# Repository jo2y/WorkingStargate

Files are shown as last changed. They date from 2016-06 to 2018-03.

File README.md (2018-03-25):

My version of the "Working" [Stargate MK II](http://www.thingiverse.com/thing:1603423) created by [Glitch](https://www.thingiverse.com/Glitch/about).

Rough list of changes made by me.
*   I rewrote most of the arduino code.
*   I merged some of the ideas from [Carasibana](
    https://www.thingiverse.com/Carasibana/about)'s [version](
    https://www.thingiverse.com/make:104604) and another build I can no longer
    find on thingiverse. This second one is where I got the audio parts.

Some videos of my completed build:
*   https://youtu.be/wpxE08CTAZk
*   https://youtu.be/otdeWcTs9Uo

I no longer have this gate. I donated it to a Stargate focused charity auction.
I plan to build a new one eventually.

Note: I am no claiming ownership of all the work in this repository, specifically the design.

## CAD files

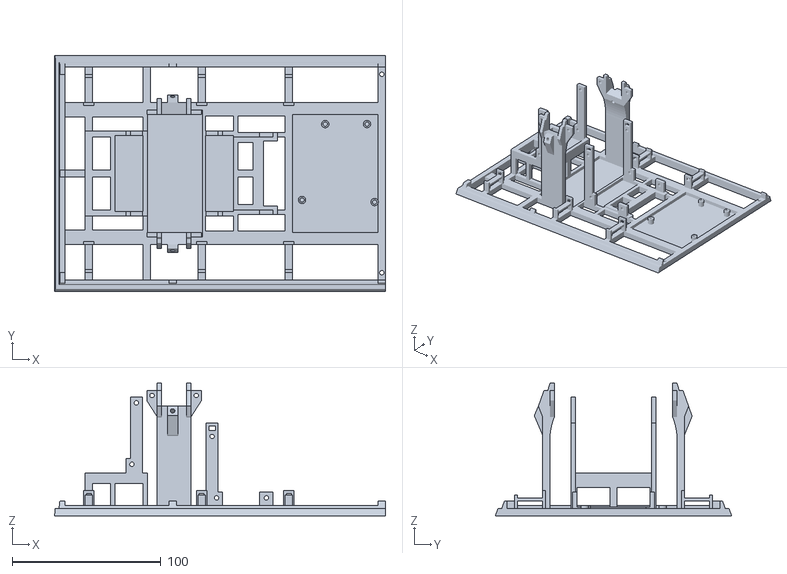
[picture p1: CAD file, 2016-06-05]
Stargate_mk2/base_full_x1.stl
222.5 x 158.8 x 89.1

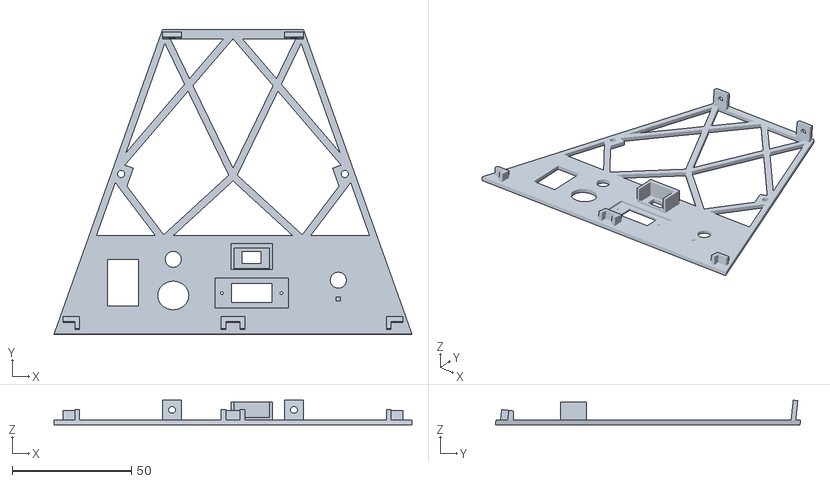
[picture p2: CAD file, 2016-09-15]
Stargate_mk2/base_rear_w_panel_v2.stl
149.9 x 127.8 x 10.4

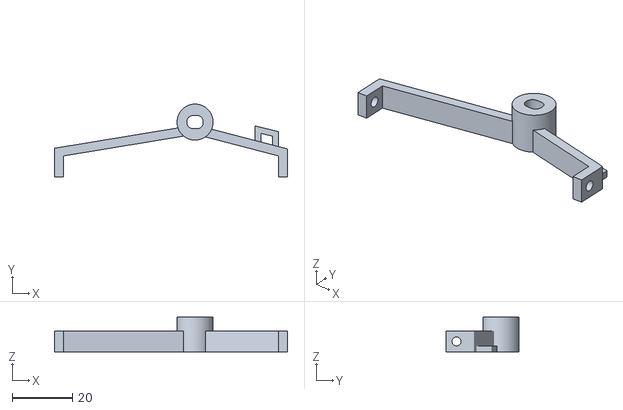
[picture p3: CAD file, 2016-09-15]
Stargate_mk2/ldr_1_enlarged_v2.stl
77.5 x 24.3 x 11.6

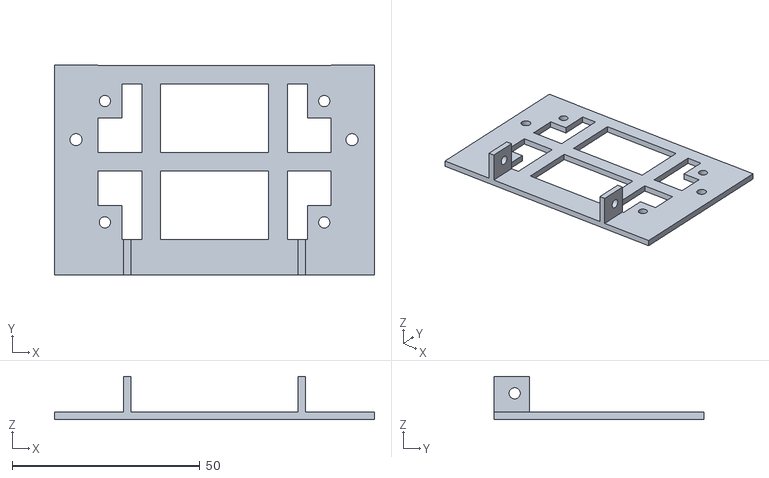
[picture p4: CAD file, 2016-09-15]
Stargate_mk2/circuit_board_permaproto.stl
85.2 x 55.9 x 11.5

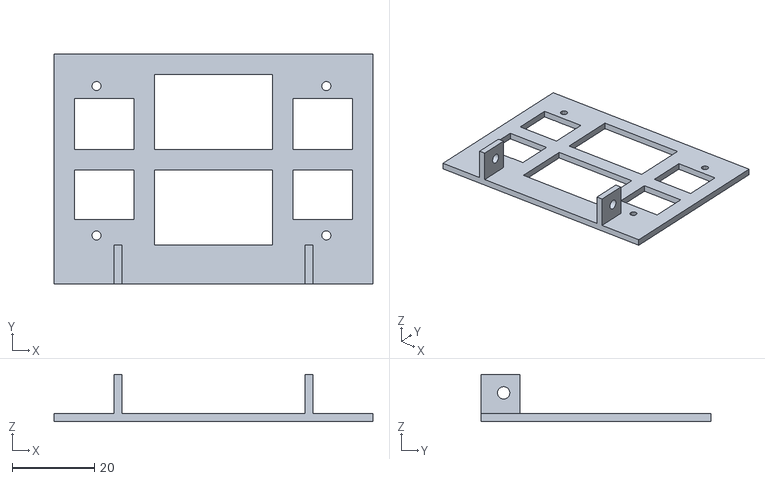
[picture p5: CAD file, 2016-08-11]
Stargate_mk2/circuit_board_4cm_x_6cm.stl
77.4 x 55.8 x 11.5

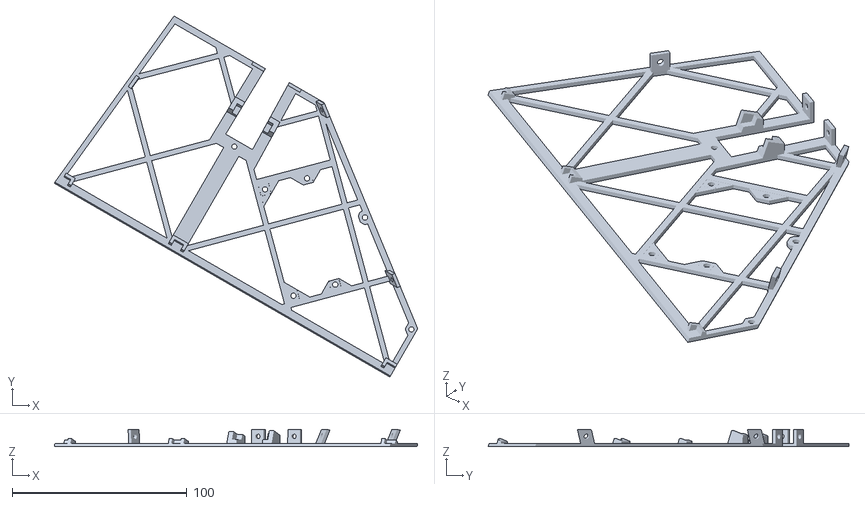
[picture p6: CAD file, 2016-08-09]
Stargate_mk2/base_right_w_speaker.stl
208.1 x 206.7 x 9.98

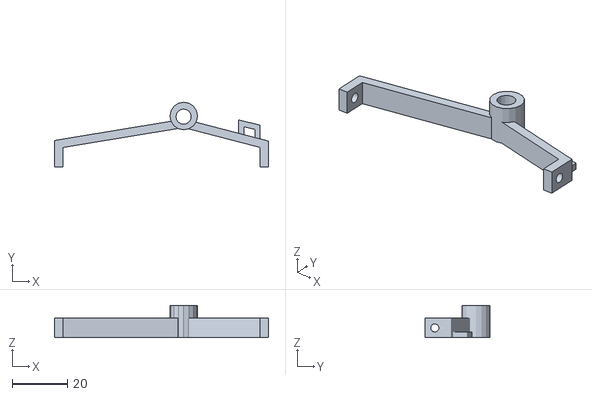
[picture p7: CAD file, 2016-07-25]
Stargate_mk2/ldr_x1_enlarged.stl
77.5 x 23.4 x 11.6

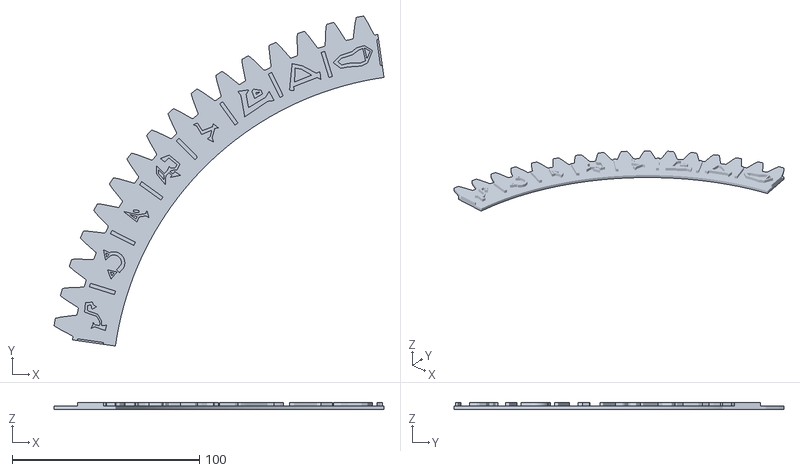
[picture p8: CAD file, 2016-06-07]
Stargate_mk2/symbol_2_x1.stl
176.0 x 176.0 x 4.00

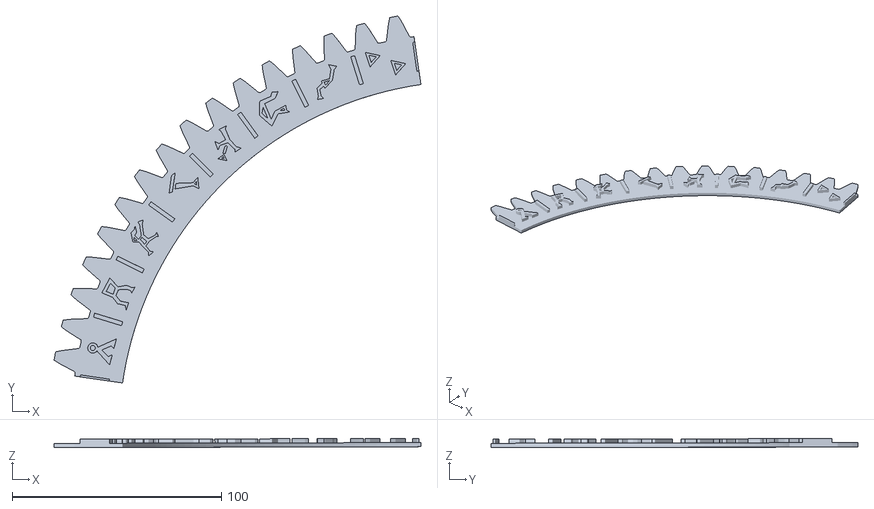
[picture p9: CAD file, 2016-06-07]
Stargate_mk2/symbol_1_x1.stl
175.4 x 175.4 x 4.42

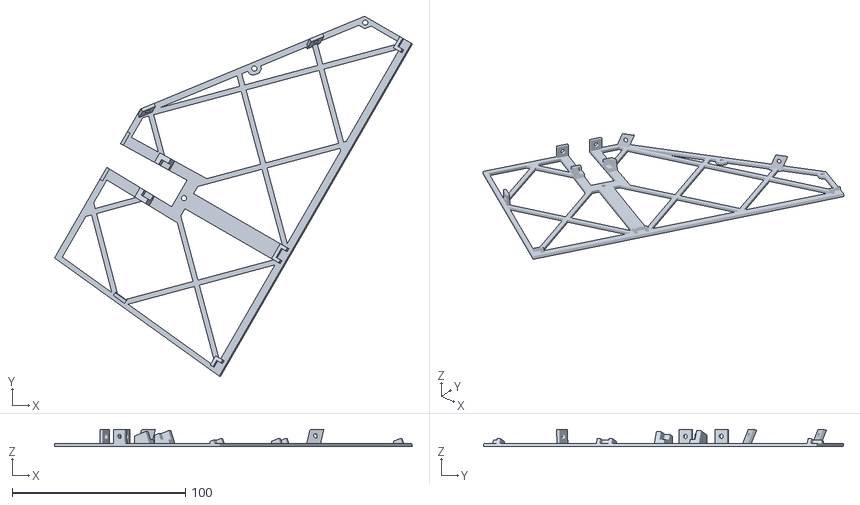
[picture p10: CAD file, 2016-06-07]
Stargate_mk2/base_r_2_x1.stl
206.7 x 208.1 x 9.98

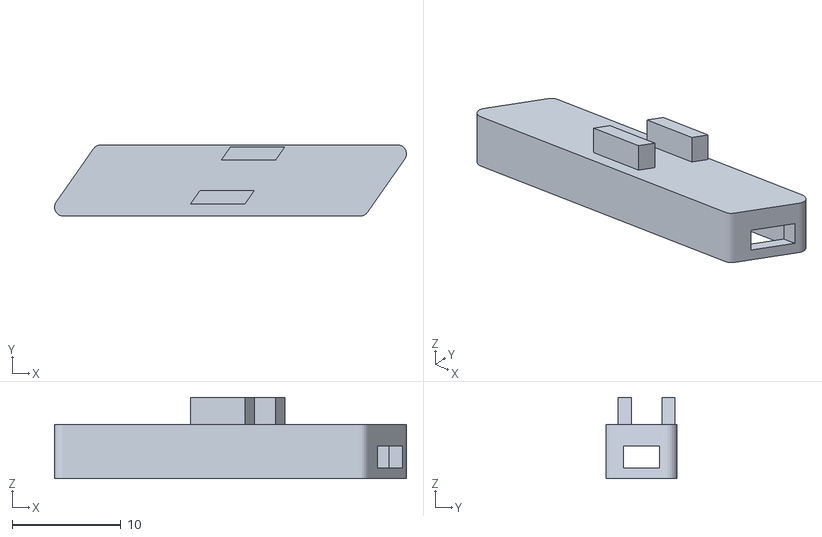
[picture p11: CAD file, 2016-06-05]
Stargate_mk2/rail_r_2_x4.stl
32.4 x 6.56 x 7.48

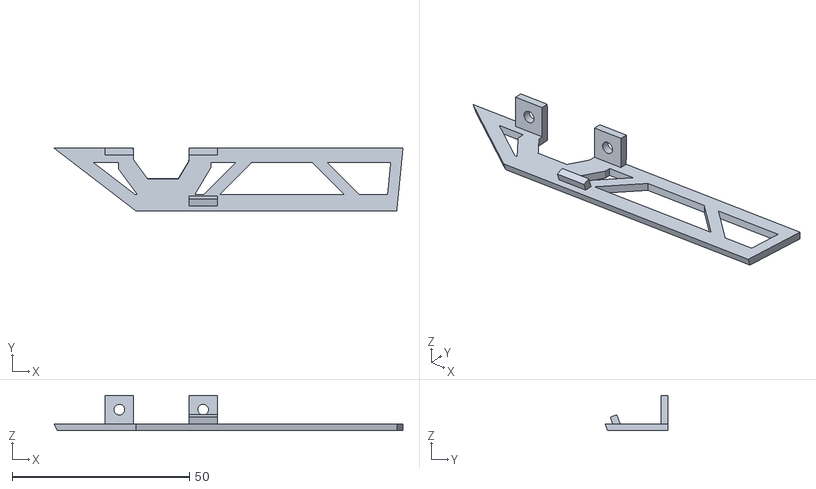
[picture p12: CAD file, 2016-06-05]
Stargate_mk2/base_r_3_x1.stl
98.5 x 17.7 x 9.90

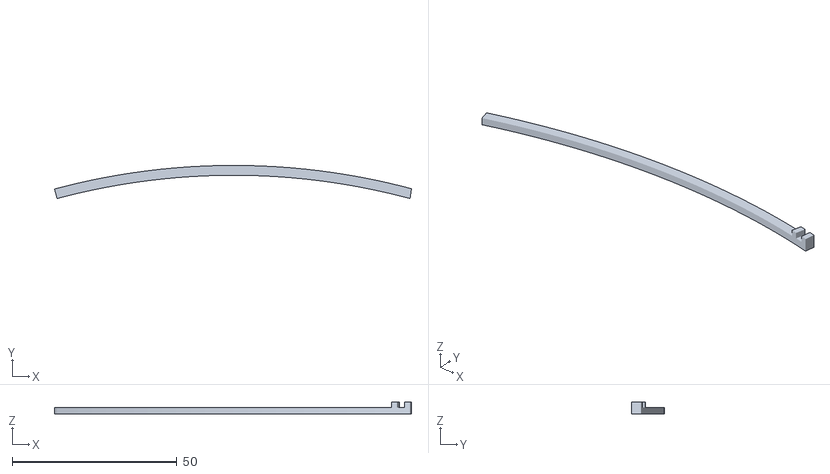
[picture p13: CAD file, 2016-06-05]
Stargate_mk2/ring_4_x1.stl
108.4 x 10.1 x 3.64

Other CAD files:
Stargate_mk2/base_left_w_speaker.stl
Stargate_mk2/symbol_3_x1.stl
Stargate_mk2/symbol_4_x1.stl
Stargate_mk2/base_l_2_x1.stl
Stargate_mk2/circuit_x.stl
Stargate_mk2/base_half_back_x1.stl
Stargate_mk2/base_half_front_x1.stl
Stargate_mk2/base_l_1_x1.stl
Stargate_mk2/base_l_3_x1.stl
Stargate_mk2/base_r_1_x1.stl
Stargate_mk2/base_rear_w_panel.stl
Stargate_mk2/base_rear_x1.stl
Stargate_mk2/chevron_1_x9.stl
Stargate_mk2/chevron_2_a_x9.stl
Stargate_mk2/chevron_2_b_x9.stl
Stargate_mk2/chevron_2_c_x9.stl
Stargate_mk2/chevron_3_a_x9.stl
Stargate_mk2/chevron_3_b_x9.stl
Stargate_mk2/chevron_3_c_x9.stl
Stargate_mk2/chevron_4_x9.stl
Stargate_mk2/gate_1_a_x8.stl
Stargate_mk2/gate_1_b_x1.stl
Stargate_mk2/gate_2_a_x8.stl
Stargate_mk2/gate_2_b_x1.stl
Stargate_mk2/gate_3_a_x1.stl
Stargate_mk2/gate_3_b_x6.stl
Stargate_mk2/gate_3_c_x1.stl
Stargate_mk2/gate_3_d_x1.stl
Stargate_mk2/gate_4_a_x1.stl
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

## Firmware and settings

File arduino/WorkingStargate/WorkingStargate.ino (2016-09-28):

// Configurable values
//
// LED and Pixel Related Settings
//
// How long should the locking chevron be engaged?
#define LOCK_DELAY 1500  // in milliseconds

//
// Arduino Pin Mappings
//
// This section defines which arduino pin connects to which electronic device.
// The data pin for the chain of NeoPixels around the gate.
#define GATE_PIXELS 5

// The left and right ramp lights. Connected to the audio board GPIO pins.
#define LEFT_RAMP 7
#define RIGHT_RAMP 6

// DHD buttons
#define DHD_OUTER A2  // Serial pin 4
#define DHD_INNER A3  // Serial pin 5
// The data pin for the chain of NeoPixels around the DHD.
#define DHD_PIXELS 8

// Calibration LDR and LED
#define CAL_LDR A1
#define CAL_LED 10

// These are the pins used for the music maker shield. If you're using the
// adafruit mp3 shield, leave as-is.
#define AUDIO_SHIELD_RESET -1  // VS1053 reset pin (unused!)
#define AUDIO_SHIELD_CS 7      // VS1053 chip select pin (output)
#define AUDIO_SHIELD_DCS 6     // VS1053 Data/command select pin (output)
#define AUDIO_CARDCS 4         // Card chip select pin
// DREQ should be an Int pin, see http://arduino.cc/en/Reference/attachInterrupt
#define AUDIO_DREQ 3           // VS1053 Data request, ideally an Interrupt pin
#define AUDIO_VOLUME A0
// MINVOL/MAXVOL should be (0, 254) with 0 being the loudest and 254 as silence.
#define MINVOL 90
#define MAXVOL 0

// Unusable pins.
// These pins have double duty. Annotating them so the dual role is not
// forgotten.
#define RX 0
#define TX 1
#define MOSI 11
#define MISO 12
#define SCK 13
#define SDA A4
#define SCL A5

//
// Stepper Motor Settings
//
// The Glyph motor moves the ring with the symbols and the Chevron motor causes
// the top chevron to move.
// If you are using adafruit stepper motors, 200.0 is likely the correct value.
// If your motor doesn't list the number of steps, look for a degrees per step
// value. Divide 360 / degrees to get the value for here. (Adafruit motors are
// 1.8 degrees per step.
#define GLYPH_MOTOR_STEPS 200.0
#define CHEVRON_MOTOR_STEPS 200.0
// The port for the adafruit motor shield. If the stepper motor is connected to
// M1/M2 set 1, for M3/M4 set 2.
#define GLYPH_MOTOR_PORT 1
#define CHEVRON_MOTOR_PORT 2
// How fast should the motors be moved? The values here are likely suitable.
#define GLYPH_MOTOR_SPEED 10  // RPMs
#define CHEVRON_MOTOR_SPEED 10  // RPMs

//
// Audio Settings
//
// The SOUND_* defines specify files on the SD card that should be played at
// certain times in a dialing sequence.
#define SOUND_CHEVRON_LOCK "CHEVRON.MP3"
#define SOUND_LONG_SPIN "ROLL.MP3"
#define SOUND_SHORT_SPIN "ROLL.MP3"
#define SOUND_WORMHOLE_CLOSING "CLOSE.MP3"
#define SOUND_WORMHOLE_OPENING "OPEN.MP3"
#define SOUND_WORMHOLE_OPEN "WORMHOLE.MP3"

//
// Debugging Settings
//
// Set DEBUG to 1 to enable Serial output, 0 to disable
#define DEBUG 0

#if DEBUG
#define debug(line) Serial.print(line)
#define debugln(line) Serial.println(line)
#else
#define debug(line)
#define debugln(line)
#endif

//
// STL Design Settings.
// Values related to the printed models. These would only change if the STL
// files were redesigned.
#define NUM_GLYPHS 39.0
#define GLYPH_GEAR_TEETH 13.0
#define GLYPH_RING_TEETH 78.0
#define GLYPH_GEAR_RATIO ( GLYPH_RING_TEETH / GLYPH_GEAR_TEETH )
#define GLYPH_RING_STEPS ( GLYPH_MOTOR_STEPS * GLYPH_GEAR_RATIO )
#define STEPS_PER_GLYPH ( GLYPH_RING_STEPS / NUM_GLYPHS )
#define NUM_PIXELS 9
#define TOP_CHEVRON 4
#define LOCK_STEPS 10

// No user servicable values below here.
#include <SD.h>
#include <Adafruit_MCP23008.h>
#include <Adafruit_MotorShield.h>
#include <Adafruit_NeoPixel.h>
#include <Adafruit_VS1053.h>

// Global objects
Adafruit_NeoPixel pixels = Adafruit_NeoPixel(
    NUM_PIXELS, GATE_PIXELS, NEO_RGB + NEO_KHZ800);
Adafruit_MotorShield AFMS = Adafruit_MotorShield();
Adafruit_StepperMotor *SMGlyph = AFMS.getStepper(
    GLYPH_MOTOR_STEPS, GLYPH_MOTOR_PORT);
Adafruit_StepperMotor *SMChevron = AFMS.getStepper(
    CHEVRON_MOTOR_STEPS, CHEVRON_MOTOR_PORT);
Adafruit_VS1053_FilePlayer audio = Adafruit_VS1053_FilePlayer(
    AUDIO_SHIELD_RESET, AUDIO_SHIELD_CS, AUDIO_SHIELD_DCS,
    AUDIO_DREQ, AUDIO_CARDCS);
Adafruit_MCP23008 extra_pins = Adafruit_MCP23008();

// Colors
uint32_t off = pixels.Color(0, 0, 0);
uint32_t on = pixels.Color(0, 255, 0);

// Pixel related functions

void initPixels() {
  pixels.begin();
  pixelsOff();
}

void lockChevron(int chevron) {
  pixels.setPixelColor(TOP_CHEVRON, on);
  pixels.show();
  debugln(F("Lowering Top Chevron."));
  startSound(SOUND_CHEVRON_LOCK);
  
  SMChevron->step(LOCK_STEPS, BACKWARD, SINGLE);
  delay(LOCK_DELAY);
  waitSound();
  debugln(F("Raising Top Chevron."));
  SMChevron->step(LOCK_STEPS, FORWARD, SINGLE);
  pixels.setPixelColor(TOP_CHEVRON, off);
  pixels.setPixelColor(chevron, on);
  pixels.show();
}

void pixelsOff() {
  for (int i = 0; i < NUM_PIXELS; i++) {
    pixels.setPixelColor(i, off);
  }
  pixels.show();
}

void initRampLights() {
  debugln(F("Initializing Ramp Lights."));
  audio.GPIO_pinMode(LEFT_RAMP, OUTPUT);
  audio.GPIO_pinMode(RIGHT_RAMP, OUTPUT);
}

void toggleRampLights(boolean left, boolean right) {
  debug(F("Turning left ramp: "));
  debugln(left ? F("On") : F("Off"));
  debug(F("Turning right ramp: "));
  debugln(right ? F("On") : F("Off"));
  audio.GPIO_digitalWrite(LEFT_RAMP, left ? HIGH : LOW);
  audio.GPIO_digitalWrite(RIGHT_RAMP, right ? HIGH : LOW);
}

// Gate Movement functions

void initMotors() {
  AFMS.begin();
  SMGlyph->setSpeed(GLYPH_MOTOR_SPEED);
  SMChevron->setSpeed(CHEVRON_MOTOR_SPEED);
  debugln(F("Raising Top Chevron."));
  SMChevron->step(10, FORWARD, SINGLE);
}

void calibrateGlyphs() {
  debugln(F("Starting Glyph Calibration."));
  // Increase the motor speed to calibrate quickly.
  SMGlyph->setSpeed(max(GLYPH_MOTOR_SPEED, 60));
  pinMode(CAL_LDR, INPUT_PULLUP);
  pinMode(CAL_LED, OUTPUT);
  digitalWrite(CAL_LED, LOW);
  float setpoint = 1024.0;
  unsigned int readings = 0;
  for (int i = 0; i < 10; ++i) {
    readings += analogRead(CAL_LDR);
    SMGlyph->step(1, BACKWARD, MICROSTEP);
  }
  setpoint = (readings / 10.0) * 0.5;
  debug(F("Setpoint: "));
  debugln(setpoint);
  digitalWrite(CAL_LED, HIGH);
  while (analogRead(CAL_LDR) > setpoint) {
    SMGlyph->step(1, FORWARD, MICROSTEP);
  }
  digitalWrite(CAL_LED, LOW);
  SMGlyph->release();
  SMGlyph->setSpeed(GLYPH_MOTOR_SPEED);
  debugln(F("Finishing Calibration."));
}

void rotateGate(int glyph, int chevron) {
  // The number of motor steps from the Earth glyph to each
  // list of glyphs in clockwise order.
  // http://rdanderson.com/stargate/glyphs/glyphs.htm
  // Explicitly declare the array size to ensure NUM_GLYPHS matches contents.
  int glyph_offsets[(int) NUM_GLYPHS] = {
    int( 0 * STEPS_PER_GLYPH), // Earth
    int(38 * STEPS_PER_GLYPH), // Crater
    int(37 * STEPS_PER_GLYPH), // Virgo
    int(36 * STEPS_PER_GLYPH), // Bootes
    int(35 * STEPS_PER_GLYPH), // Centaurus
    int(34 * STEPS_PER_GLYPH), // Libra
    int(33 * STEPS_PER_GLYPH), // Serpens Caput
    int(32 * STEPS_PER_GLYPH), // Norma
    int(31 * STEPS_PER_GLYPH), // Scorpio
    int(30 * STEPS_PER_GLYPH), // Cra
    int(29 * STEPS_PER_GLYPH), // Scutum
    int(28 * STEPS_PER_GLYPH), // Sagittarius
    int(27 * STEPS_PER_GLYPH), // Aquila
    int(26 * STEPS_PER_GLYPH), // Mic
    int(25 * STEPS_PER_GLYPH), // Capricon
    int(24 * STEPS_PER_GLYPH), // Pisces Austrinus
    int(23 * STEPS_PER_GLYPH), // Equuleus
    int(22 * STEPS_PER_GLYPH), // Aquarius
    int(21 * STEPS_PER_GLYPH), // Pegasus
    int(20 * STEPS_PER_GLYPH), // Sculptor
    int(19 * STEPS_PER_GLYPH), // Pisces
    int(18 * STEPS_PER_GLYPH), // Andromeda
    int(17 * STEPS_PER_GLYPH), // Triangulum
    int(16 * STEPS_PER_GLYPH), // Aries
    int(15 * STEPS_PER_GLYPH), // Perseus
    int(14 * STEPS_PER_GLYPH), // Cetus
    int(13 * STEPS_PER_GLYPH), // Taurus
    int(12 * STEPS_PER_GLYPH), // Auriga
    int(11 * STEPS_PER_GLYPH), // Eridanus
    int(10 * STEPS_PER_GLYPH), // Orion
    int( 9 * STEPS_PER_GLYPH), // Canis Minor
    int( 8 * STEPS_PER_GLYPH), // Monoceros
    int( 7 * STEPS_PER_GLYPH), // Gemini
    int( 6 * STEPS_PER_GLYPH), // Hydra
    int( 5 * STEPS_PER_GLYPH), // Lynx
    int( 4 * STEPS_PER_GLYPH), // Cancer
    int( 3 * STEPS_PER_GLYPH), // Sextans
    int( 2 * STEPS_PER_GLYPH), // Leo Minor
    int( 1 * STEPS_PER_GLYPH), // Leo
  };

  // Assume the gate starts with Earth at the top.
  static int curr_offset = glyph_offsets[0];
  int direction = (chevron % 2) ? FORWARD : BACKWARD;
  int steps = 0;

  // Bounds checking before we access glyph_offsets.
  glyph = constrain(glyph, 0, NUM_GLYPHS);

  int offset = glyph_offsets[glyph];
  if (direction == FORWARD) {
    steps = offset - curr_offset;
  } else if (direction == BACKWARD) {
    steps = curr_offset - offset;
  }
  // Keep the rotation within a single rotation of the gate.
  while (steps < 0) {
    steps += GLYPH_RING_STEPS;
  }
  while (steps > GLYPH_RING_STEPS) {
    steps -= GLYPH_RING_STEPS;
  }

  debug(F("Moving "));
  debug(steps);
  debug(F(" steps "));
  debug((direction == FORWARD) ? F("Forward") : F("Backward"));
  debug(F(" to glyph "));
  debug(glyph);
  debug(F(" for chevron "));
  debugln(chevron);
  startSound(SOUND_SHORT_SPIN);
  // TODO(jo2y): Update rotate to take into account partial steps.
  SMGlyph->step((int) steps, direction, SINGLE);
  stopSound(2000);
  curr_offset = glyph_offsets[glyph];
}

void initAudio() {
  debugln(F("Starting Audio."));
  if (!audio.begin()) {
    debugln(F("Audio shield did not initialize."));
#if DEBUG
    audio.dumpRegs();
#endif
  }
  setVolume();
  audio.useInterrupt(VS1053_FILEPLAYER_PIN_INT);
}

void setVolume() {
  static int oldvol = int((MINVOL + MAXVOL) / 2);
  byte attempts = 20;
  while (attempts > 0) {
    --attempts;
    int vol = analogRead(AUDIO_VOLUME);
    // analogRead will return (0, 1023) and setVolume takes (0, 254), but values
    // larger than 90 seem too quiet to hear, so scale (0, 1024) to (0, 90).
    // 0 is full volume and 254 is silence.
    // 255 will activate analog shutdown mode.
    vol = map(vol, 0, 1023, MINVOL, MAXVOL);
    // Sometimes we get noise from the ADC, so constrain the jumps in volume
    // to something sane. If the volume truly was changed a lot, we will
    // gradually converge on the new setting.
    vol = constrain(vol, oldvol - 5, oldvol + 5);
    if (oldvol != vol) {
      if (abs(oldvol - vol) > 2) {
        // Avoid spamming serial if the volume is fluctuating by a small amount
        // due to electrical noise.
        debug(F("Changing volume to: "));
        debugln(vol);
      }
      audio.setVolume(vol, vol);
    } else {
      debugln(F("Volume Stabilized."));
      return;
    }
    oldvol = vol;
  }
  debugln(F("Volume attempts exceeded."));
}

void startSound(const char *file) {
  debug(F("Playing file: "));
  debugln(file);
  setVolume();
  if (!audio.startPlayingFile(file)) {
    debug(F("Could not open file: "));
    debugln(file);
  }
}

void waitSound() {
  debugln(F("Waiting for track to end."));
  setVolume();
  while(audio.playingMusic) {
    delay(100);
    setVolume();
  }
}

void stopSound(int sleep) {
  debugln(F("Interrupting audio."));
  setVolume();
  delay(sleep);
  audio.stopPlaying();
}

void initSD() {
  debugln(F("Initializing SD Card."));
  SD.begin(AUDIO_CARDCS);
}

void initExtraPins() {
  debugln(F("Initializing the MCP23008."));
  extra_pins.begin();
  for (int x = 0; x < 8; ++x) {
    extra_pins.pinMode(x, INPUT);
    extra_pins.pullUp(x, HIGH);
  }
}

void dialAddress(byte *address, int length) {
  length = constrain(length, 0, 8);
  byte chevron = 5;
  byte max_chevron = 7;
  byte min_chevron = 1;
  if (length > 6) max_chevron = 8;
  if (length > 7) min_chevron = 0;
  debugln(F("Starting dialing sequence."));
  for (int position = 0; (position < length); ++position) {
    debug(F("Locking in Chevron "));
    debugln(chevron);
    byte glyph = address[position];
    glyph = constrain(glyph, 0, NUM_GLYPHS);
    rotateGate(glyph, chevron);
    lockChevron(chevron);
    ++chevron;
    if (chevron > max_chevron) chevron = min_chevron;
  }
  rotateGate(0, TOP_CHEVRON);
  lockChevron(chevron);
  openGate();
}

void openGate() {
  startSound(SOUND_WORMHOLE_OPENING);
  waitSound();
  startSound(SOUND_WORMHOLE_OPEN);
  waitSound();
  pixelsOff();
  startSound(SOUND_WORMHOLE_CLOSING);
  pixelsOff();
  waitSound();
}

void randomDialing() {
  // List of addresses provided by
  // http://www.rdanderson.com/stargate/glyphs/glyphs.htm
  // Addresses with missing symbols were skipped.
  byte milky_addresses[][6] = {
    {27, 7, 15, 32, 12, 30}, // Abydos
//    {20, 18, 11, 38, 10, 32}, // Apophis' Base
//    {20, 2, 35, 8, 26, 15}, // Camelot
//    {29, 3, 6, 9, 12, 16}, // Castiana
//    {29, 18, 19, 20, 21, 22}, // Sahal
//    {9, 2, 23, 15, 37, 20}, // Chulak
//    {14, 21, 16, 11, 30, 7}, // Clava Thesara Infinitas
//    {26, 20, 35, 32, 23, 4}, // Clava Thesara Infinitas (again?)
//    {3, 32, 16, 8, 10, 12}, // Destroyers
//    {28, 38, 35, 9, 15, 3}, // Edora
//    {30, 37, 9, 7, 18, 16}, // Euronda
//    {29, 8, 18, 22, 4, 25}, // Juna
//    {6, 16, 8, 3, 26, 25}, // Kallana
//    {26, 35, 6, 8, 23, 14}, // Kheb
//    {18, 2, 30, 12, 26, 33}, // K'Tau
//    {24, 12, 32, 7, 11, 34}, // Martin's Homeworld (destroyed)
//    {38, 28, 15, 35, 3, 19}, // NID Off-world Base
//    {28, 8, 16, 33, 13, 31}, // P2X-555
//    {38, 9, 28, 15, 35, 3}, // P34-353J
//    {19, 8, 4, 37, 26, 16}, // P3W-451 (Black hole planet)
//    {9, 26, 34, 27, 17, 21}, // P3X-118
//    {3, 28, 9, 35, 24, 15}, // P3X-562
//    {25, 8, 18, 29, 4, 22}, // P9C-372
//    {12, 36, 23, 18, 7, 27}, // PB5-926
//    {35, 3, 31, 29, 5, 17}, // Praclarush Taonas
//    {30, 19, 34, 9, 33, 18}, // Sangreal Planet
//    {33, 28, 23, 26, 16, 21}, // Tartarus
//    {6, 33, 27, 37, 11, 18}, // Tollan (destroyed)
//    {4, 29, 8, 22, 18, 25}, // Tollana
//    {3, 8, 2, 12, 19, 30}, // Vagon Brei
//    {9, 18, 27, 15, 21, 36}, // Unnammed Planet from Unending
  };
  
  // Special gate addresses.
//  byte earth[] = {28, 26, 5, 36, 11, 29};
//  byte othana[] = {11, 27, 23, 16, 33, 3, 9};

  static int chevron = 5;
  debugln(F("Starting dialing sequence."));
  debug(F("Locking in Chevron "));
  debugln(chevron);

  byte length = sizeof(milky_addresses[0]) / sizeof(byte);
  byte addresses = sizeof(milky_addresses) / length / sizeof(byte);
  byte *address = milky_addresses[random(addresses - 1)];
  debug(F("Dialing: "));
  for (int i = 0; i < length; ++i) {
    debug(address[i]);
    debug(F(", "));
  }
  debugln();
  dialAddress(address, length);
}

void setup() {
#if DEBUG
  Serial.begin(9600);
#endif
  debugln(F("Working Stargate MKII."));
  debugln(F("Initializing."));

  // Ideally we would use an analog pin that is not connected to anything else
  // to ensure the value is real random noise. However, all the pins are
  // allocated to something. Using CAL_LDR + AUDIO_VOLUME means randomness will
  // will be based on ambient light conditions and the last set volume.
  int seed = analogRead(CAL_LDR);
  debug(F("Random seed: "));
  debugln(seed);
  randomSeed(seed);

  initExtraPins();
  initPixels();
  initMotors();
  initAudio();
  initSD();
  initRampLights();
  toggleRampLights(true, true);
  calibrateGlyphs();
  debugln(F("Initialization Complete."));
}

void loop() {
  randomDialing();
}

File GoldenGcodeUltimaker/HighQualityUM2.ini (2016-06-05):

[profile]
layer_height = 0.06
wall_thickness = 1.2
retraction_enable = True
solid_layer_thickness = 1.2
fill_density = 0
print_speed = 50
print_temperature = 210
print_temperature2 = 0
print_temperature3 = 0
print_temperature4 = 0
print_temperature5 = 0
print_bed_temperature = 70
support = None
platform_adhesion = None
support_dual_extrusion = Both
wipe_tower = False
wipe_tower_volume = 15
ooze_shield = False
filament_diameter = 2.85
filament_diameter2 = 0
filament_diameter3 = 0
filament_diameter4 = 0
filament_diameter5 = 0
filament_flow = 100.0
nozzle_size = 0.4
retraction_speed = 40.0
retraction_amount = 4.5
retraction_dual_amount = 16.5
retraction_min_travel = 1
retraction_combing = All
retraction_minimal_extrusion = 0.05
retraction_hop = 0.1
bottom_thickness = 0.3
layer0_width_factor = 100
object_sink = 0.0
overlap_dual = 0.15
travel_speed = 200
bottom_layer_speed = 20
infill_speed = 0.0
solidarea_speed = 0.0
inset0_speed = 0.0
insetx_speed = 0.0
cool_min_layer_time = 5
fan_enabled = True
skirt_line_count = 1
skirt_gap = 3.0
skirt_minimal_length = 150.0
fan_full_height = 5.0
fan_speed = 100
fan_speed_max = 100
cool_min_feedrate = 10
cool_head_lift = True
solid_top = True
solid_bottom = True
fill_overlap = 15
perimeter_before_infill = False
support_type = Lines
support_angle = 60
support_fill_rate = 15
support_xy_distance = 0.7
support_z_distance = 0.15
spiralize = False
simple_mode = False
brim_line_count = 20
raft_margin = 5.0
raft_line_spacing = 3.0
raft_base_thickness = 0.3
raft_base_linewidth = 1.0
raft_interface_thickness = 0.27
raft_interface_linewidth = 0.4
raft_airgap_all = 0.0
raft_airgap = 0.22
raft_surface_layers = 2
raft_surface_thickness = 0.27
raft_surface_linewidth = 0.4
fix_horrible_union_all_type_a = True
fix_horrible_union_all_type_b = False
fix_horrible_use_open_bits = False
fix_horrible_extensive_stitching = False
plugin_config = 
object_center_x = -1
object_center_y = -1

[alterations]
start.gcode = ;Sliced at: {day} {date} {time}
	;Basic settings: Layer height: {layer_height} Walls: {wall_thickness} Fill: {fill_density}
	;Print time: {print_time}
	;Filament used: {filament_amount}m {filament_weight}g
	;Filament cost: {filament_cost}
	;M190 S{print_bed_temperature} ;Uncomment to add your own bed temperature line
	;M109 S{print_temperature} ;Uncomment to add your own temperature line
	G21        ;metric values
	G90        ;absolute positioning
	M82        ;set extruder to absolute mode
	M107       ;start with the fan off
	G28 X0 Y0  ;move X/Y to min endstops
	G28 Z0     ;move Z to min endstops
	G1 Z15.0 F{travel_speed} ;move the platform down 15mm
	G92 E0                  ;zero the extruded length
	G1 F200 E3              ;extrude 3mm of feed stock
	G92 E0                  ;zero the extruded length again
	G1 F{travel_speed}
	;Put printing message on LCD screen
	M117 Printing...
end.gcode = ;End GCode
	M104 S0                     ;extruder heater off
	M140 S0                     ;heated bed heater off (if you have it)
	G91                                    ;relative positioning
	G1 E-1 F300                            ;retract the filament a bit before lifting the nozzle, to release some of the pressure
	G1 Z+0.5 E-5 X-20 Y-20 F{travel_speed} ;move Z up a bit and retract filament even more
	G28 X0 Y0                              ;move X/Y to min endstops, so the head is out of the way
	M84                         ;steppers off
	G90                         ;absolute positioning
	;{profile_string}
start2.gcode = ;Sliced at: {day} {date} {time}
	;Basic settings: Layer height: {layer_height} Walls: {wall_thickness} Fill: {fill_density}
	;Print time: {print_time}
	;Filament used: {filament_amount}m {filament_weight}g
	;Filament cost: {filament_cost}
	;M190 S{print_bed_temperature} ;Uncomment to add your own bed temperature line
	;M104 S{print_temperature} ;Uncomment to add your own temperature line
	;M109 T1 S{print_temperature2} ;Uncomment to add your own temperature line
	;M109 T0 S{print_temperature} ;Uncomment to add your own temperature line
	G21        ;metric values
	G90        ;absolute positioning
	M107       ;start with the fan off
	G28 X0 Y0  ;move X/Y to min endstops
	G28 Z0     ;move Z to min endstops
	G1 Z15.0 F{travel_speed} ;move the platform down 15mm
	T1                      ;Switch to the 2nd extruder
	G92 E0                  ;zero the extruded length
	G1 F200 E10             ;extrude 10mm of feed stock
	G92 E0                  ;zero the extruded length again
	G1 F200 E-{retraction_dual_amount}
	T0                      ;Switch to the first extruder
	G92 E0                  ;zero the extruded length
	G1 F200 E10             ;extrude 10mm of feed stock
	G92 E0                  ;zero the extruded length again
	G1 F{travel_speed}
	;Put printing message on LCD screen
	M117 Printing...
end2.gcode = ;End GCode
	M104 T0 S0                     ;extruder heater off
	M104 T1 S0                     ;extruder heater off
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

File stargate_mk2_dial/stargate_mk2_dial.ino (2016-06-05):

/* 
Arduino dialling and calibration script for Stargate Mk2 by Glitch
http://www.glitch.org.uk

This script is released as Attribution-NonCommercial-ShareAlike 4.0 International (CC BY-NC-SA 4.0)
http://creativecommons.org/licenses/by-nc-sa/4.0/
*/

#include <Wire.h>
#include <Adafruit_MotorShield.h>
#include "utility/Adafruit_MS_PWMServoDriver.h"

/*
Stepper motor for chevron
Create the motor shield object with the default I2C address
Connect a stepper motor with 200 steps per revolution (1.8 degree)
to motor port #1 (M1 and M2)
*/
Adafruit_MotorShield AFMS = Adafruit_MotorShield(); 
Adafruit_StepperMotor *SMChevron = AFMS.getStepper(200, 1);

/*
Stepper  motor for symbol ring
Connect a stepper motor with 200 steps per revolution (1.8 degree)
to motor port #1 (M1 and M2)
*/
Adafruit_StepperMotor *SMGate = AFMS.getStepper(200, 2);

/*
Populate Chevrons[] array with output pins according to each chevron in dialling order.
Note: pins 0 & 1 cannot be used while the Arduino is connected to a PC
For this reason the pins defined by default start from 2.
*/
//int Chevrons[] = {7,8,9,3,4,5,10,2,6};
int Chevrons[] = {5,6,7,10,2,3,8,11,4};

//Chevron_Locked should be set to the last chevron in the dialling sequence
int Chevron_Locked = Chevrons[8];

//Ramp_Lights is the output pin wired to the ramp lights (this assumes all lights are connected to a single pin).
int Ramp_Lights = 12;

//Calibrate_LED is the output pin wired to the calibration led.
//int Calibrate_LED = 11;
int Calibrate_LED = 9;

//LDR is the analogue input pin wired to the light dependant resistor.
int LDR = 0;

//Set Cal to 0 for calibration and then dialling.
//Set Cal to 3 to bypass calibration and jump to dialling.
int Cal = 0;

//The calibration point is set 3% higher than the average. Adjust this number if you experience problems with calibration.
int  Calibration_Percent = 3;

//How long should the locked chevron be lit before continuing dialling. Default is 1500 (1.5 seconds).
int ChevronLocked = 1500;

//How many steps the stepper motor must turn per symbol.
//This value is overritten by the calibrate function.
//If you bypass calibration this value must be set accordingly.
float Step_Per_Symbol = 30.77;

//How many steps to move the stepper motor for the chevron.
int Chevron_Step = 10;

//Sample Startgate addresses. un-comment the address you want.
//Abydos
int Address[] = {27,7,15,32,12,30,1};

//Othala (Asgard homeworld)
//int Address[] = {11,27,23,16,33,3,9,1};

//Destiny
//int Address[] = {6,17,21,31,35,24,5,11,1};

//Other variable definitions. No need to change these.
float LDR_avg = 0.0;
float LDR_cal = 0.0;
int Dialling = 0;
float Step_increment = 0;
int Address_Length = 0;

void setup() {
  Serial.begin(9600);  // set up Serial library at 9600 bps
  Serial.println("Working Stargate Mk2");
  AFMS.begin();  // create with the default frequency 1.6KHz
  
  SMGate->setSpeed(10);  // 10 rpm 
  SMChevron->setSpeed(10);  // 10 rpm 
  for (int tmp_chevron = 0; tmp_chevron < 9; tmp_chevron ++){
    pinMode(Chevrons[tmp_chevron], OUTPUT);
  }
  pinMode(Calibrate_LED, OUTPUT);
  pinMode(LDR,INPUT);
  pinMode(Ramp_Lights, OUTPUT);
  Address_Length = sizeof (Address) / sizeof(int);

  if (Cal == 3){
    Dialling = 1;
  }else{
    Cal = 0;
    Dialling = 0;
  }
}

void loop() {
  if (Cal < 3){
    calibrate();
  }else if (Dialling <= Address_Length){
    dial(Dialling);
    if (Dialling == Address_Length){
      SMChevron->step(Chevron_Step, FORWARD, SINGLE);
      SMChevron->release();
      Serial.println("Wormhole Established");
      for (int tmp_chevron1 = 0; tmp_chevron1 < 9; tmp_chevron1 ++){
        digitalWrite(Chevrons[tmp_chevron1], HIGH);
      }
      digitalWrite(Ramp_Lights, HIGH);
      delay(10000);
      for (int tmp_chevron = 0; tmp_chevron < 9; tmp_chevron ++){
        digitalWrite(Chevrons[tmp_chevron], LOW);
      }
      digitalWrite(Ramp_Lights, LOW);
      Serial.println("Wormhole Disengaged");
    }
    Dialling ++;
  }
}

void dial(int Chevron) {
  Serial.print("Chevron ");
  Serial.print(Chevron);
  Serial.println(" Encoded");
  int Steps_Turn = 0;
  if (Chevron == 1) {
    Steps_Turn = round(Step_Per_Symbol * (Address[(Chevron - 1)] - 1));
    SMGate->step(Steps_Turn, BACKWARD, DOUBLE);
  }else{
    Steps_Turn = Address[(Chevron - 1)] - Address[(Chevron - 2)];
    if ((Chevron % 2) == 0) {
      if  (Steps_Turn < 0) {
        Steps_Turn = Steps_Turn * -1;
      }else{
        Steps_Turn = 39 - Steps_Turn;
      }
      Steps_Turn = round(Step_Per_Symbol * Steps_Turn);
      SMGate->step(Steps_Turn, FORWARD, DOUBLE);
    }else{
      if  (Steps_Turn < 0) {
        Steps_Turn = 39 + Steps_Turn;
      }
      Steps_Turn = round(Step_Per_Symbol * Steps_Turn);
      SMGate->step(Steps_Turn, BACKWARD, DOUBLE);
    }
  } 
  SMGate->release();
  if ((Dialling == 9) && (Address[(Chevron - 1)] != 1)){
    for (int tmp_fail_safe_gate = 0; tmp_fail_safe_gate <= 100; tmp_fail_safe_gate ++){
      int tmp_fail_safe_chevron = random(7);
      digitalWrite(Chevrons[tmp_fail_safe_chevron], LOW);
      SMGate->step(5, BACKWARD, DOUBLE);
      SMGate->release();
      digitalWrite(Chevrons[tmp_fail_safe_chevron], HIGH);
    }
    for (int tmp_chevron = 0; tmp_chevron < 9; tmp_chevron ++){
      digitalWrite(Chevrons[tmp_chevron], LOW);
    }
    Dialling = 10;
  }else{
    Serial.print("Chevron ");
    Serial.print(Chevron);
    Serial.println(" Locked");
    digitalWrite(Chevron_Locked, HIGH);
    SMChevron->step(Chevron_Step, BACKWARD, SINGLE);
    SMChevron->release();
  }
  if (Dialling < Address_Length){
    delay(ChevronLocked);
    SMChevron->step(Chevron_Step, FORWARD, SINGLE);
    SMChevron->release();
    digitalWrite(Chevron_Locked, LOW);
    delay(20);
    if ((Address_Length < 8) || (Dialling < 4)){
      digitalWrite(Chevrons[(Chevron - 1)], HIGH);
    }else if ((Address_Length == 8) && ((Dialling >= 4) && (Dialling <= Address_Length))){
      if (Dialling == 4){
        digitalWrite(Chevrons[(6)], HIGH);
      }else if (Dialling == 5){
        digitalWrite(Chevrons[(3)], HIGH);
      }else if (Dialling == 6){
        digitalWrite(Chevrons[(4)], HIGH);
      }else if (Dialling == 7){
        digitalWrite(Chevrons[(5)], HIGH);
      }
    }else if ((Address_Length == 9) && ((Dialling >= 4) && (Dialling <= Address_Length))){
      if (Dialling == 4){
        digitalWrite(Chevrons[(6)], HIGH);
      }else if (Dialling == 5){
        digitalWrite(Chevrons[(7)], HIGH);
      }else if (Dialling == 6){
        digitalWrite(Chevrons[(3)], HIGH);
      }else if (Dialling == 7){
        digitalWrite(Chevrons[(4)], HIGH);
      }else if (Dialling == 8){
        digitalWrite(Chevrons[(5)], HIGH);
      }
    }
  }
}
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

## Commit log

2016-06-05 Original versions of Glitch's MK2 version of the Stargate. http://www.thingiverse.com/thing:1603423
    [base_full_x1.stl, base_half_back_x1.stl, base_half_front_x1.stl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]
2016-06-07 Rename cura profiles to be a little more descriptive of their use-case.
2016-06-07 Rotate these objects to they fit onto the UM2 build plate.
    [base_l_2_x1.stl, base_r_2_x1.stl, symbol_1_x1.stl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]
2016-07-05 Reslice these models that failed to print properly.
2016-07-24 Reslice with 100% infill to help strength and slower print speed to help with bridging.
2016-07-24 Create multi-object versions of these models to speed printing.
2016-07-24 ldr_x1.stl modified to hold a 5mm photo sensor.
    [ldr_x1_enlarged.stl]
2016-07-25 Increase the inner hole diameter to account for the 0.5mm lost when printing.
    [ldr_x1_enlarged.stl]
2016-07-25 Reslice with 0.6 nozzle and settings to make these print properly. - flip ramp_4 180 degrees so bevelled edge is not an overhang. - Disable 'fix holes' in cura so it doesn't treat the intended holes 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
2016-07-26 Add multi-object versions of these to printer prep time.
2016-07-26 Add multi-object versions of these to save printer prep time.
2016-08-09 Add modified version of the left and right side to accommodate a speaker. https://www.adafruit.com/products/1669
    [base_left_w_speaker.stl, base_right_w_speaker.stl]
2016-08-09 Add a multiobject version that prints a pair at a time.
2016-08-11 Add a modified version of circuit_x.stl that works with 'Double Sided Protoboard Prototyping PCB Board 4cm x 6cm'. https://smile.amazon.com/gp/product/B00NQ37V0K
    [circuit_board_4cm_x_6cm.stl]
2016-08-13 Add a modified base rear with a panel for buttons.
    [base_rear_w_panel.stl]
2016-09-15 Move the arduino code under the MK2 directory.
2016-09-15 Modify the circuit board stl to fit an Adafruit half perma proto board.
    [circuit_board_permaproto.stl]
2016-09-15 Add a larger version of the LDR holder to work with the LDR from sparkfun.
    [ldr_1_enlarged_v2.stl]
2016-09-15 New backpanel with power input, power switch, push button, slide switch, serial port, and volume knob.
    [base_rear_w_panel_v2.stl]
2016-09-15 Remove the sineTest because it doesn't seem to respect the volume setting and is unneeded.
    [WorkingStargate.ino]
2016-09-16 Add a basic calibration of the glyphs to put the Earth symbol at the top.
2016-09-18 Annotate the end of calibration.
2016-09-19 Update the calibration method to use the sample and setpoint method.
2016-09-19 Fix a bug in calibrateGlyph where it would fail to exit if the ring was already calibrated.
    [WorkingStargate.ino]
2016-09-19 Correctly bounds check the number of steps to be less than the number of glyph ring steps and not the number of motor steps.
    [WorkingStargate.ino]
2016-09-19 Quickly set the initial volume so it doesn't take several seconds of audio to reach the set value.
    [WorkingStargate.ino]
2016-09-19 Fix a missing ).
    [WorkingStargate.ino]
2016-09-19 Fix a typo. s/NUMGLYPHS/NUM_GLYPHS/.
    [WorkingStargate.ino]
2016-09-19 Fix a typo. Bound the range on the number of steps, and not the gear ratio.
    [WorkingStargate.ino]
2016-09-19 Switch from int to byte for gate addresses to save memory.
2016-09-28 Save resliced versions used in the final print.
